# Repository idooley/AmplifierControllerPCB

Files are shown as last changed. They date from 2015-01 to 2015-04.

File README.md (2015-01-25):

## Overview
This repo contains a design for a PCB that holds an ATMEGA microcontroller and corresponding interfaces that would be useful to control an amplifier. Some possible uses:

* Convert a surround-sound receiver into a multi-channel amplifier by removing everything except the power amplifier section and power supply. Use the outputs from this controller board to drive the power supply switching relay and any speaker protection relays. Use the inputs on this controller to interface with a thermal sensor (like the LM61CIZ used in an Onkyo TX-SR705) and a trigger input to turn on the amplifier. The ATMEGA can be programmed to drive LEDs indicating the amplifier's state, and apply delays to protect the system during startup.
* Build your own power amplifier that includes thermal management, trigger inputs/outputs, and delayed relay firing at startup for protection circuits.

Overall, this PCB is quite similar to an Arduino, but with a little extra circuitry, and not as many general I/O pins exposed as such.

Some things you'll find in the repo:
* DipTrace schematic files and PCB layouts
* PCB gerbers (both for the crossover circuit PCB and a corresponding dual-rail power supply)
* Code for the ATMega
** A simple LED blinking program
** A makefile that contains an avrdude command that can set the fuses appropriately to get the chip to run at 16Mhz on an external crystal
** My code that switches on/off the main power relay inside the Onkyo based on an input trigger signal (isolated using an opto-isolator).
* Pictures of the results

## Isaac Dooley's DIY Project

This is simply a DIY hobby project under work by Isaac Dooley. I am no expert in these matters, but hopefully this thing will work fine.

Some known issues with the initial 2015/01/04 version:
* Silk-screened text on the PCB overlaps the pads of the ATMEGA 168.
* The PWM 1 output is connected to a non-PWM-capable pin on the ATMEGA 168. It should be moved to the unused PWM pin nearby.
* The switch inputs leave the pins floating, which won't work very well. The right way to do this is to use the internal pull-up resistor on these pins, and have the switch instead go from the pin to ground.

My first attempt was a bit of a failures. First I set bad fuse values on the ATMEGA168, making it impossible to program it further or modify the fuse values (without a high-voltage programmer). Then I broke some pads on the PCB while trying to unsolder the chip to replace it.

The second attempt however is a success so far! I'm able to set the fuses correctly and program the ATMEGA168 to blink the 4 LEDs on the PCB. Next I'll solder on the input/output circuitry components to verify those parts work as required. Here is a photo of the functional PCB so far:

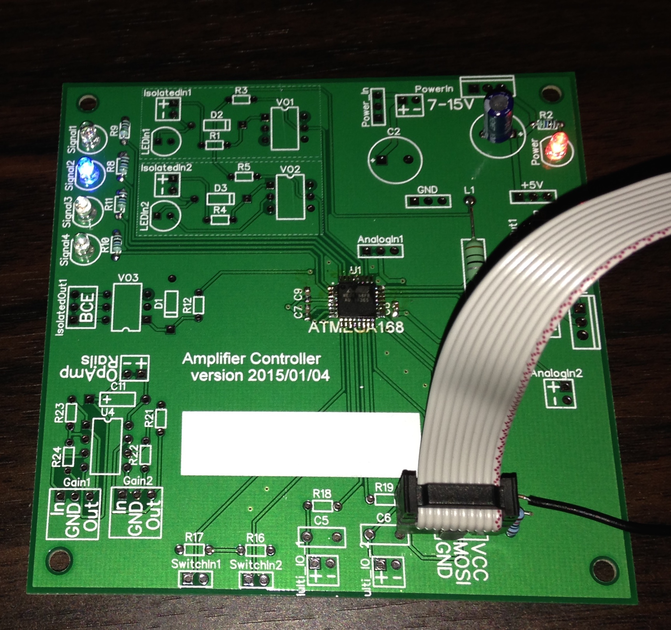
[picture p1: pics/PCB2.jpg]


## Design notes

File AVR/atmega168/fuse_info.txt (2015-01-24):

Original fuse settings on the atmega168pb:

MacBookPro2:atmega168 isaacdooley$ avrdude -c arduino -b 19200 -P /dev/tty.usbmodem1411 -p atmega168p -u -U lfuse:r:-:h -U hfuse:r:-:h -U efuse:r:-:h -F

avrdude: AVR device initialized and ready to accept instructions

Reading | ################################################## | 100% 0.01s

avrdude: Device signature = 0x1e9415
avrdude: Expected signature for ATmega168P is 1E 94 0B
avrdude: reading lfuse memory:

Reading | ################################################## | 100% 0.02s

avrdude: writing output file "<stdout>"
0x62
avrdude: reading hfuse memory:

Reading | ################################################## | 100% 0.02s

avrdude: writing output file "<stdout>"
0xdf
avrdude: reading efuse memory:

Reading | ################################################## | 100% 0.02s

avrdude: writing output file "<stdout>"
0x1

avrdude done.  Thank you.

> avrdude -c arduino -b 19200 -P /dev/tty.usbmodem1411 -p atmega168p -u -U lfuse:r:-:i -U hfuse:r:-:i -U efuse:r:-:i -F

avrdude: AVR device initialized and ready to accept instructions

Reading | ################################################## | 100% 0.01s

avrdude: Device signature = 0x1e9415
avrdude: Expected signature for ATmega168P is 1E 94 0B
avrdude: reading lfuse memory:

Reading | ################################################## | 100% 0.02s

avrdude: writing output file "<stdout>"
:01000000629D
:00000001FF
avrdude: reading hfuse memory:

Reading | ################################################## | 100% 0.02s

avrdude: writing output file "<stdout>"
:01000000DF20
:00000001FF
avrdude: reading efuse memory:

Reading | ################################################## | 100% 0.02s

avrdude: writing output file "<stdout>"
:0100000001FE
:00000001FF

avrdude done.  Thank you.

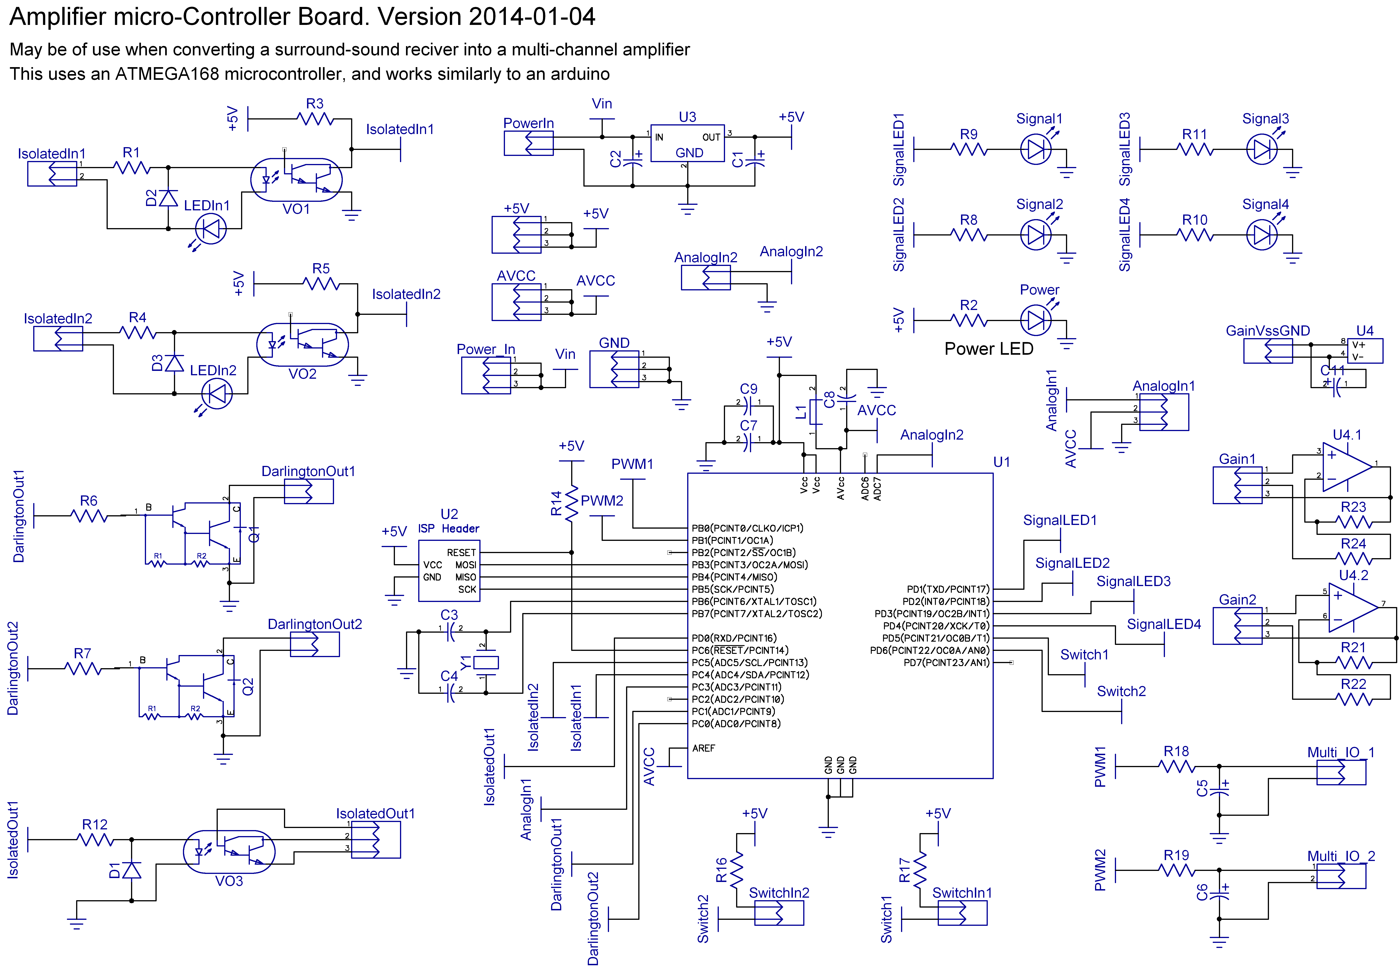
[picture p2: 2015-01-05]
pics/Schematic.png

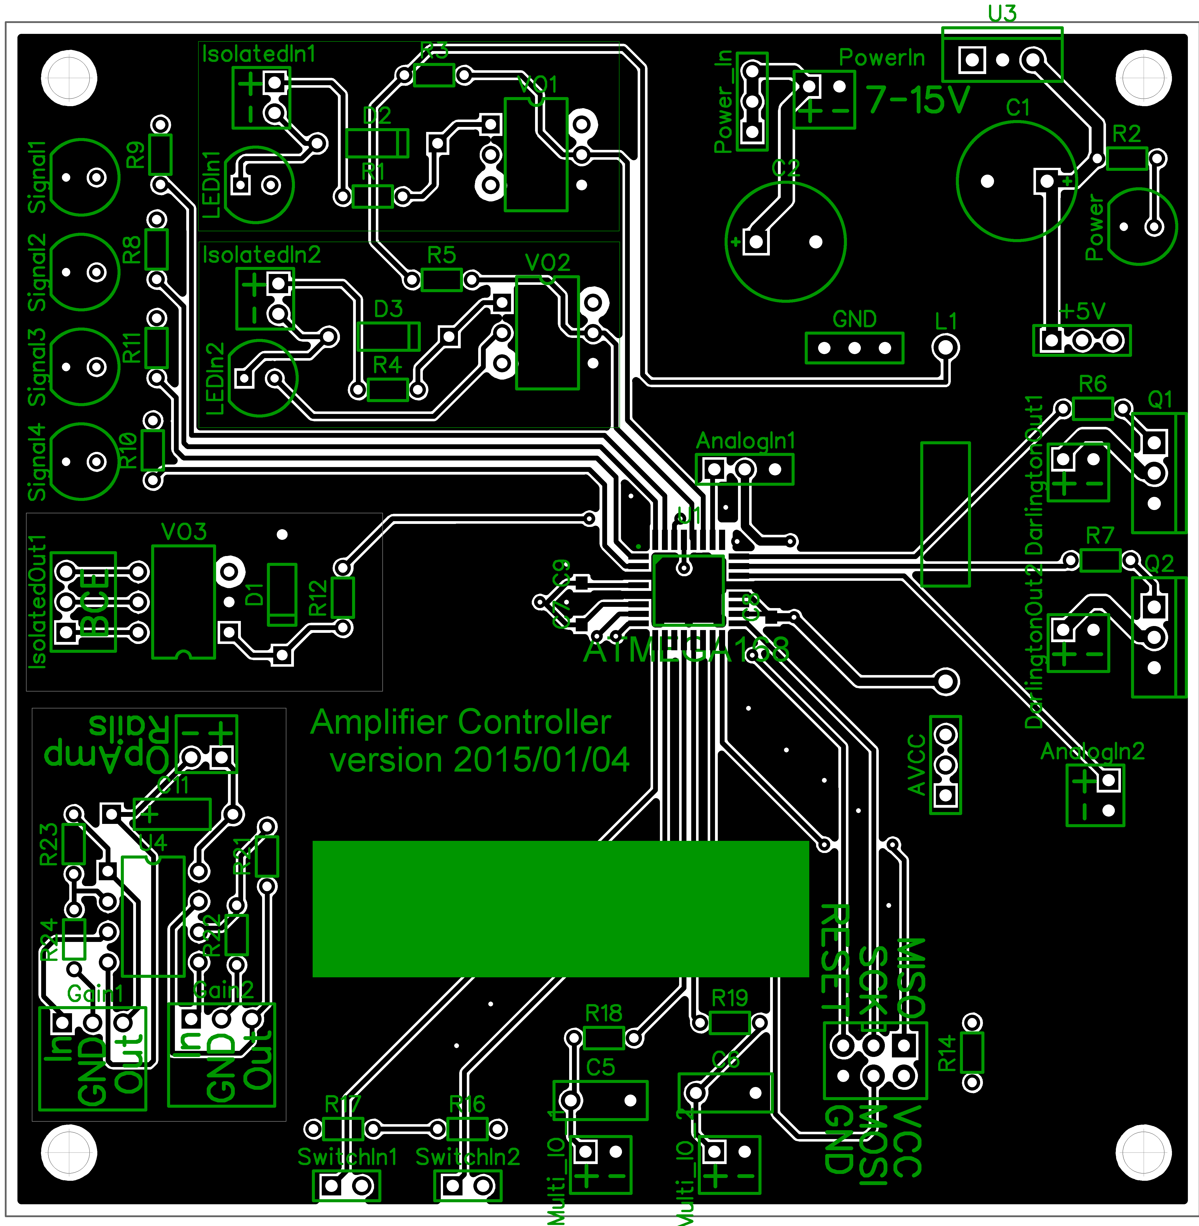
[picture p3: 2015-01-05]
pics/PCB.png

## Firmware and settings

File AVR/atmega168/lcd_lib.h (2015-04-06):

//*****************************************************************************
//
// File Name	: 'lcd_lib.h'
// Title		: 8 and 4 bit LCd interface + mixed pins modes
// Author		: Scienceprog.com - Copyright (C) 2007
// Created		: 2007-03-29
// Revised		: 2011-12-13
// Version		: 2.0
// Target MCU	: Atmel AVR series
//
// This code is distributed under the GNU Public License
//		which can be found at http://www.gnu.org/licenses/gpl.txt
//
//*****************************************************************************
#ifndef LCD_LIB
#define LCD_LIB

#include <inttypes.h>


//Uncomment one of these if
//LCD 4 bit interface is used (single port pins)
//#define LCD_4BIT 
//LCD 8 bit interface is used (single port pins)
//#define LCD_8BIT 
//LCD 4 bit interface is used (mixed port pins)
#define LCD_4BIT_M 
//LCD 8 bit interface is used (mixed port pins)
//#define LCD_8BIT_M 
//******************************************************

#define LCD_RS	2 	//define MCU pin connected to LCD RS
#define LCD_RW	3 	//define MCU pin connected to LCD R/W
#define LCD_E	4	//define MCU pin connected to LCD E
#define LCD_D0	7	//define MCU pin connected to LCD D0
#define LCD_D1	7	//define MCU pin connected to LCD D1
#define LCD_D2	7	//define MCU pin connected to LCD D2
#define LCD_D3	7	//define MCU pin connected to LCD D3
#define LCD_D4	0	//define MCU pin connected to LCD D4
#define LCD_D5	1	//define MCU pin connected to LCD D5
#define LCD_D6	2	//define MCU pin connected to LCD D6
#define LCD_D7	3	//define MCU pin connected to LCD D7

	

#if defined (LCD_4BIT_M) || defined (LCD_8BIT_M)
#define LDPRS PORTB		//RS pin assignment
#define LDDRS DDRB
#define LDPRW PORTB		//RW pin assignment
#define LDDRW DDRB
#define LDPE PORTB		//E pin assignment
#define LDDE DDRB
#define LDPD0 PORTC		//D0 pin assignment
#define LDDD0 DDRC
#define LDPD1 PORTD		//D1 pin assignment
#define LDDD1 DDRD
#define LDPD2 PORTC		//D2 pin assignment
#define LDDD2 DDRC
#define LDPD3 PORTB		//D3 pin assignment
#define LDDD3 DDRB
#define LDPD4 PORTC		//D4 pin assignment
#define LDDD4 DDRC
#define LDPD5 PORTC		//D5 pin assignment
#define LDDD5 DDRC
#define LDPD6 PORTC		//D6 pin assignment
#define LDDD6 DDRC
#define LDPD7 PORTC		//D7 pin assignment
#define LDDD7 DDRC
#endif

#if defined (LCD_4BIT) || defined (LCD_8BIT) //if aligned mode
#define LDP PORTD	//define MCU port connected to LCD data pins
#define LCP PORTD	//define MCU port connected to LCD control pins
#define LDDR DDRD	//define MCU direction register for port connected to LCD data pins
#define LCDR DDRD	//define MCU direction register for port connected to LCD control pins
#endif


#define LCD_CLR             0	//DB0: clear display
#define LCD_HOME            1	//DB1: return to home position
#define LCD_ENTRY_MODE      2	//DB2: set entry mode
#define LCD_ENTRY_INC       1	//DB1: increment
#define LCD_ENTRY_SHIFT     0	//DB2: shift
#define LCD_ON_CTRL         3	//DB3: turn lcd/cursor on
#define LCD_ON_DISPLAY      2	//DB2: turn display on
#define LCD_ON_CURSOR       1	//DB1: turn cursor on
#define LCD_ON_BLINK        0	//DB0: blinking cursor
#define LCD_MOVE            4	//DB4: move cursor/display
#define LCD_MOVE_DISP       3	//DB3: move display (0-> move cursor)
#define LCD_MOVE_RIGHT      2	//DB2: move right (0-> left)
#define LCD_FUNCTION        5	//DB5: function set
#define LCD_FUNCTION_8BIT   4	//DB4: set 8BIT mode (0->4BIT mode)
#define LCD_FUNCTION_2LINES 3	//DB3: two lines (0->one line)
#define LCD_FUNCTION_10DOTS 2	//DB2: 5x10 font (0->5x7 font)
#define LCD_CGRAM           6	//DB6: set CG RAM address
#define LCD_DDRAM           7	//DB7: set DD RAM address
// reading:
#define LCD_BUSY            7	//DB7: LCD is busy
#define LCD_LINES			2	//visible lines
#define LCD_LINE_LENGTH		16	//line length (in characters)
// cursor position to DDRAM mapping
#define LCD_LINE0_DDRAMADDR		0x00
#define LCD_LINE1_DDRAMADDR		0x40
#define LCD_LINE2_DDRAMADDR		0x14
#define LCD_LINE3_DDRAMADDR		0x54
// progress bar defines
#define PROGRESSPIXELS_PER_CHAR	6


void LCDsendChar(uint8_t);		//forms data ready to send to LCD
void LCDsendCommand(uint8_t);	//forms data ready to send to LCD
void LCDinit(void);			//Initializes LCD
void LCDclr(void);				//Clears LCD
void LCDhome(void);			//LCD cursor home
void LCDstring(uint8_t*, uint8_t);	//Outputs string to LCD
void LCDGotoXY(uint8_t, uint8_t);	//Cursor to X Y position
void CopyStringtoLCD(const uint8_t*, uint8_t, uint8_t);//copies flash string to LCD at x,y
void LCDdefinechar(const uint8_t *,uint8_t);//write char to LCD CGRAM 
void LCDshiftRight(uint8_t);	//shift by n characters Right
void LCDshiftLeft(uint8_t);	//shift by n characters Left
void LCDcursorOn(void);		//Underline cursor ON
void LCDcursorOnBlink(void);	//Underline blinking cursor ON
void LCDcursorOFF(void);		//Cursor OFF
void LCDblank(void);			//LCD blank but not cleared
void LCDvisible(void);			//LCD visible
void LCDcursorLeft(uint8_t);	//Shift cursor left by n
void LCDcursorRight(uint8_t);	//shif cursor right by n
// displays a horizontal progress bar at the current cursor location
// <progress> is the value the bargraph should indicate
// <maxprogress> is the value at the end of the bargraph
// <length> is the number of LCD characters that the bargraph should cover
//adapted from AVRLIB - displays progress only for 8 bit variables
void LCDprogressBar(uint8_t progress, uint8_t maxprogress, uint8_t length);


#endif

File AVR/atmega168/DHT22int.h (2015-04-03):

/* Copyright 2014 Miguel Moreto
 *
 * This file is part of DHT22 Interrupt Driven library for AVR.
 *
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
 * Please consult the GNU General Public License at http://www.gnu.org/licenses/.
 */

/*
 * DHT22int.h
 *
 * Version 1
 *
 * Header file of the DHT22 Interrupt Driven library for AVR.
 * Created: 12/01/2014 22:25:54
 * Author: Miguel Moreto

 *
 * IMPORTANT: You need to modify this file accordingly with your microcontroller,
 *            the external interrupt used (and the pin) and the timer.
 *
 * This file is configured to the following situation:
 *    Microcontroller: ATmega328P
 *    Timer: 8bit Timer 2
 *    Pin: PD2 => INT0 pin
 *    8MHz clock from internal RC oscillator.
 *    Divide by 8 fuse not programmed (clock is not divided by 8).
 *
 * This config should also work with ATmega48A(PA), ATmega88A(PA),
 * ATmega168A(PA) and ATmega328.
 *
 * Please, see the comments at the .c file about how the lib works and how to use it.
 */


#ifndef DHT22INT_H_
#define DHT22INT_H_

/* Driver Configuration */
#define OVERFLOWS_HOST_START 2 // How many times a timer overflow is used to generate Period P1.
#define DHT22_DATA_BIT_COUNT 40 // Number of bits that the sensor send.

/* Macros: */
#define PIN_LOW(port,pin) port &= ~(1<<pin)
#define PIN_HIGH(port,pin) port |= (1<<pin)
#define SET_PIN_INPUT(portdir,pin) portdir &= ~(1<<pin)
#define SET_PIN_OUTPUT(portdir,pin) portdir |= (1<<pin)
#define PIN_TOGGLE(port,pin) port ^= (1<<pin)

/* Pin definition (change accordingly) 
   The pin must be a INT pin. Pin Change Interrupt is not sopported yet. */
#define DHT22_PIN PIND2 // INT0
#define DHT22_DDR DDRD
#define DHT22_PORT PORTD

/* User define macros. Please change this macros accordingly with the microcontroller,
   pin, the timer and also the external interrupt that you are using.
   
   IMPORTANT: You must configure the timer with a prescaler such that the tick
              is 1us, this means a timer clock freq. of 1MHz. With 8MHz clock, you
			  can set the prescaler to divide by 8. */
#define TIMER_SETUP_CTC					TCCR2A = (1 << WGM21);   // Code to configure the timer in CTC mode.
#define TIMER_ENABLE_CTC_INTERRUPT		TIMSK2 = (1 << OCIE2A);  // Code to enable Compare Match Interrupt
#define TIMER_OCR_REGISTER				OCR2A			// Timer output compare register.
#define TIMER_COUNTER_REGISTER			TCNT2			// Timer counter register
#define TIMER_START						TCCR2B = (1 << CS21); // Code to start timer with 1MHz clock
#define TIMER_STOP						TCCR2B = 0; // Code to stop the timer by writing 0 in prescaler bits.
#define EXT_INTERRUPT_DISABLE			EIMSK &= ~(1 << INT0); // Code to disable the external interrupt used.
#define EXT_INTERRUPT_ENABLE			EIMSK |= (1 << INT0);  // Code to enable the external interrupt used.
#define EXT_INTERRUPT_SET_RISING_EDGE	EICRA |= (1 << ISC01) | (1 << ISC00); // Code to set the interrupt to rising edge
#define EXT_INTERRUPT_SET_FALLING_EDGE	EICRA |= (1 << ISC01); EICRA &= ~(1 << ISC00);  // Code to set the interrupt to falling edge
#define EXT_INTERRUPT_CLEAR_FLAG		EIFR |= (1 << INTF0);  // Code to clear the external interrupt flag.

/* Interrupt vectors. Change accordingly */
#define TIMER_CTC_VECTOR				TIMER2_COMPA_vect
#define EXT_INTERRUPT_VECTOR			INT0_vect

/* Typedef of a enumeration of the possible states and error status */
typedef enum
{
	DHT_STOPPED = 0,
	DHT_HOST_START,
	DHT_HOST_PULLUP,
	DHT_WAIT_SENSOR_RESPONSE,
	DHT_SENSOR_PULLUP,
	DHT_TRANSFERING,
	DHT_CHECK_CRC,
	DHT_DATA_READY,
	DHT_ERROR_NOT_RESPOND,
	DHT_ERROR_CHECKSUM,
	DHT_BUSY,
	DHT_STARTED,
} DHT22_STATE_t;

/* Typedef of the structure that holds the sensor values */
typedef struct
{
	int8_t temperature_integral;
	uint8_t temperature_decimal;
	uint8_t humidity_integral;
	uint8_t humidity_decimal;
} DHT22_DATA_t;

/* Function prototypes */
void DHT22_Init(void);
DHT22_STATE_t DHT22_StartReading(void);
DHT22_STATE_t DHT22_CheckStatus(DHT22_DATA_t* data);


#endif /* DHT22INT_H_ */

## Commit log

2015-01-05 Initial commit with Schematic and PCB files
2015-01-05 Add gerbers
    [AmpControllerPCB.GBL, AmpControllerPCB.GBO, AmpControllerPCB.GBS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]
2015-01-24 Add simple LED blinking program, and makefile capable of setting fuses
2015-01-24 Adding picture of PCB succesfully blinking the LEDs
2015-01-25 Added note to schematic
2015-01-31 Adding second generation controller board design. This one supports ethernet, USB, an LCD display, and a more powerful AVR chip.
2015-02-04 Switch makefile to use USBasp programmer
2015-03-30 Add lcd driver code
2015-04-03 Add DHT22 sensor library

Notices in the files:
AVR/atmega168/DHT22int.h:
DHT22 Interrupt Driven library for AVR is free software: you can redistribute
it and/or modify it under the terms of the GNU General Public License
